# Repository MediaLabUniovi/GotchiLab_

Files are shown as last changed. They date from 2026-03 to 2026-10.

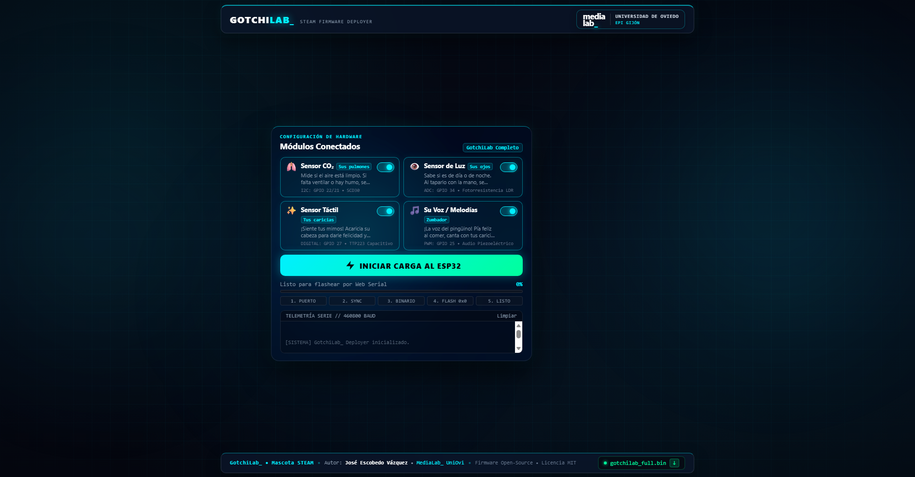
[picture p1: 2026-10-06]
docs/capturas/spotlight_capture.png

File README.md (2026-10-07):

# GotchiLab_








---

<div align="center">

  <a href="https://gotchilab.medialab-uniovi.es/" target="_blank" rel="noopener noreferrer">
    PULSA AQUÍ PARA CARGAR TU ESP32 ONLINE
  </a>

</div>

---

**GotchiLab_** es una mascota electrónica interactiva de código abierto diseñada y desarrollada en **MediaLab_** para talleres educativos de tecnología y divulgación **STEAM** (Ciencia, Tecnología, Ingeniería, Arte y Matemáticas).

La criatura virtual es un pingüino animado que habita en una pantalla OLED monocromática de 128x64 píxeles gobernada por un microcontrolador **ESP32 DevKit v1**. El firmware reacciona tanto a estímulos directos del usuario (pulsador de alimentación, caricias táctiles capacitivas, conmutador de sonido) como a magnitudes físicas ambientales (nivel de luminosidad mediante fotorresistencia LDR y concentración de dióxido de carbono $CO_2$ mediante sensor óptico NDIR).

---

## Índice

1. [Objetivos Educativos STEAM](#1-objetivos-educativos-steam)
2. [Arquitectura del Firmware y Ciclo de Vida](#2-arquitectura-del-firmware-y-ciclo-de-vida)
3. [Asignación de Pines (Pinout Unificado)](#3-asignación-de-pines-pinout-unificado)
4. [Ajuste y Calibración Analógica del Divisor LDR](#4-ajuste-y-calibración-analógica-del-divisor-ldr)
5. [Bypass Hardware de CO2: Modo Ferias y Demostraciones](#5-bypass-hardware-de-co2-modo-ferias-y-demostraciones)
6. [Máquina de Estados y Secuencia Gráfica de Muerte](#6-máquina-de-estados-y-secuencia-gráfica-de-muerte)
7. [Ciclo de Vida Autocontenido (Sin Persistencia)](#7-ciclo-de-vida-autocontenido-sin-persistencia)
8. [Guía de Compilación y Carga con PlatformIO](#8-guía-de-compilación-y-carga-con-platformio)
9. [GotchiLab_ Web Deployer & Flasheador Web Oficial (V4)](#9-gotchilab_-web-deployer--flasheador-web-oficial-v4)
10. [Estructura del Proyecto](#10-estructura-del-proyecto)
11. [Licencia](#11-licencia)

---

## 1. Objetivos Educativos STEAM

El proyecto busca desmitificar el desarrollo de sistemas embebidos mediante una experiencia tangible:
- **Electrónica Analógica y Digital**: Comprensión práctica de divisores resistivos, saturación de sensores LDR, buses de comunicación serie ($I^2C$), transductores piezoeléctricos PWM y sensores capacitivos táctiles.
- **Calidad del Aire y Conciencia Ambiental**: Introducción a la física de gases y sensores infrarrojos no dispersivos (NDIR) con el Sensirion SCD30, relacionando la concentración de $CO_2$ en recintos cerrados con la salud de la mascota.
- **Ingeniería de Software para Sistemas Embebidos**: Implementación de una Máquina de Estados Finita (FSM), eliminación de bloqueos (`delay()`) en favor de contadores no bloqueantes con `millis()`, gestión de buffers gráficos en RAM y modularidad tolerante a ausencias de hardware.

---

## 2. Arquitectura del Firmware y Ciclo de Vida

El sistema opera bajo un bucle cooperativo en tiempo real gobernado por `code/src/main.cpp`:
- **Capa Gráfica**: 15 cuadros monocromáticos de 128x64 píxeles por animación (1024 bytes/cuadro empaquetados en memoria Flash), renderizados a 5 FPS (200 ms por cuadro) con offsets verticales dinámicos.
- **Audio PWM**: Controlador de sonido sobre el canal 0 del generador LEDC del ESP32 con secuencias de notas no bloqueantes y conmutación de silencio por hardware.
- **Monitor de Constantes Vitales**: Evaluación periódica de hambre, afecto, fatiga por vigilia prolongada y toxicidad por $CO_2$.

```mermaid
flowchart TD
    EGG([Huevo IDLE_EGG]) -->|Toque TTP223 / Auto| BIRTH([Nacimiento BIRTH])
    BIRTH --> IDLE([Reposo Saludable IDLE])
    
    IDLE -->|Pulsador| FEED([Comiendo FEED])
    FEED --> IDLE
    
    IDLE -->|Toque TTP223| PET([Caricia PET])
    PET --> IDLE
    
    IDLE -->|Oscuridad LDR| SLEEP([Durmiendo SLEEP])
    SLEEP -->|Luz LDR| IDLE
    
    IDLE -->|CO2 >= 1600 ppm| T_UNHEALTHY([Transicion Enfermo])
    T_UNHEALTHY --> SICK([Reposo Enfermo IDLE_UNHEALTHY])
    SICK -->|CO2 <= 1100 ppm| T_HEALTHY([Transicion Sano])
    T_HEALTHY --> IDLE
    
    IDLE -.->|Inanicion / CO2 / Agotamiento / Spam| POP([Explosion POP - 15 Frames])
    SICK -.->|Inanicion / CO2 / Agotamiento| POP
    
    POP --> DEAD([Pantalla Game Over y Puntuacion])
    DEAD -->|Timeout 9s / Reset Pulsador tras 1.5s| EGG
```

---

## 3. Asignación de Pines (Pinout Unificado)

La arquitectura centraliza la asignación de pines en `code/include/pins_config.h`:

| Periférico / Señal | Pin ESP32 | Modo GPIO | Descripción Técnica |
| :--- | :---: | :---: | :--- |
| **I2C SDA** (OLED & SCD30) | `GPIO 22` | $I^2C$ Data | Bus de datos bidireccional compartido |
| **I2C SCL** (OLED & SCD30) | `GPIO 21` | $I^2C$ Clock | Señal de reloj de bus serie compartido |
| **Pulsador Alimentar** | `GPIO 33` | `INPUT_PULLUP` | Pulsador activo a nivel bajo (GND) |
| **Sensor Táctil (TTP223)** | `GPIO 27` | `INPUT` | Entrada digital activa a nivel alto (VCC) |
| **Sensor de Luz (LDR)** | `GPIO 34` | `ADC1_CH6` | Entrada analógica (solo lectura, sin pull-up) |
| **Buzzer Piezoeléctrico** | `GPIO 26` | Salida LEDC | Modulación PWM (Canal 0, 8 bits) |
| **Conmutador Silencio (Mute)** | `GPIO 32` | `INPUT_PULLUP` | Puente a GND conmuta entre sonido y silencio |
| **Modo Ferias (Bypass CO2)** | `GPIO 25` | `INPUT_PULLUP` | Jumper a GND: anula inicialización de $CO_2$ |

---

## 4. Ajuste y Calibración Analógica del Divisor LDR

### Topología del Circuito
El sensor de luz implementa un divisor de tensión resistivo entre la línea de 3.3V y masa:

```text
       3.3V (VCC)
           │
         ┌─┴─┐
         │LDR│ (Fotorresistencia)
         └─┬─┘
           ├───────> GPIO 34 (ADC1_CH6 del ESP32)
         ┌─┴─┐
         │10k│ (Resistencia Pull-Down de 10 kΩ)
         └─┬─┘
           │
          GND
```

### Ecuación de Transferencia
$$V_{out} = V_{CC} \cdot \left( \frac{R_{pull}}{R_{LDR} + R_{pull}} \right)$$

$$\text{Cuentas ADC (12 bits)} = \left( \frac{V_{out}}{3.3\,\text{V}} \right) \cdot 4095$$

- **En luz ambiente**: La resistencia $R_{LDR}$ cae a valores bajos (~1 kΩ a 5 kΩ), por lo que $V_{out} \approx 2.75\,\text{V}$ (ADC $\approx 3412$).
- **En oscuridad (tapado)**: La resistencia $R_{LDR}$ aumenta drásticamente (> 50 kΩ a 100+ kΩ), por lo que $V_{out}$ cae por debajo de $1.0\,\text{V}$ (ADC < 1240).

### Calibración Paso a Paso con Multímetro
1. Configura el multímetro en escala de tensión continua (**DC Voltios**, rango 20V o 2V).
2. Conecta la sonda negra a **GND** y la sonda roja al punto medio del divisor (**GPIO 34**).
3. Mide la tensión en condiciones de iluminación de trabajo ($V_{luz} \approx 2.5\,\text{V} - 3.0\,\text{V}$).
4. Cubre completamente la fotorresistencia con el dedo y anota la tensión mínima ($V_{oscuro} \approx 0.5\,\text{V} - 1.5\,\text{V}$).
5. Establece el punto de conmutación en el valor medio:
   $$V_{umbral} = \frac{V_{luz} + V_{oscuro}}{2}$$
   $$\text{LDR\_DARK\_THRESHOLD} = \left(\frac{V_{umbral}}{3.3\,\text{V}}\right) \cdot 4095$$
6. Actualiza la constante `LDR_DARK_THRESHOLD` en `code/include/config.h` (valor predeterminado: **2856**, correspondiente a ~2.30V).

### Telemetría Serie de Depuración
Para verificar lecturas en tiempo real sin cálculos manuales, activa la directiva en `code/include/config.h`:
```cpp
#define DEBUG_LDR_CALIBRATION 1
```
Abre la consola serie a **115200 baudios** para observar el volcado continuo:
```text
[LDR DEBUG] ADC Raw: 3120/4095 | Voltaje: 2.512 V | Umbral: 2856 | Estado: ILUMINADO (DESPIERTO)
[LDR DEBUG] ADC Raw: 1150/4095 | Voltaje: 0.926 V | Umbral: 2856 | Estado: OSCURO (DORMIR)
```

---

## 5. Bypass Hardware de CO2: Modo Ferias y Demostraciones

En eventos masivos, ferias de ciencias o aulas cerradas, la concentración de $CO_2$ suele superar con facilidad los 1600 ppm, provocando que la mascota enferme continuamente o muera por asfixia en menos de un minuto durante las explicaciones.

Para solventarlo sin recompilar el código:
1. **Jumper Físico**: Se define `PIN_FAIR_MODE` en `GPIO 25` configurado con `INPUT_PULLUP`.
2. **Detección en Arranque**: Durante el `setup()`, el microcontrolador verifica el estado de `GPIO 25`:
   - Si está conectado a **GND** mediante un jumper o cable Dupont:
     - Se omite la inicialización de la librería del sensor SCD30 y el tráfico por el bus $I^2C$.
     - La variable interna `co2SensorEnabled` pasa a `false`.
     - Las lecturas devuelven un valor nominal limpio y constante de **400 ppm**.
     - La máquina de estados ignora totalmente las penalizaciones y alertas respiratorias.
   - Si el jumper está abierto (flotante / HIGH): El sensor NDIR opera con normalidad.

### Exclusión Completa en Compilación
Si se construye una versión económica de la mascota sin el sensor Sensirion SCD30 instalado físicamente, puede excluirse íntegramente del binario definiendo en `code/include/config.h`:
```cpp
#define USE_CO2_SENSOR 0
```

---

## 6. Máquina de Estados y Secuencia Gráfica de Muerte

Para ofrecer un dramatismo lúdico intuitivo y eliminar transiciones abruptas:

1. **Detección de Fallecimiento**: Cuando se cumple cualquier condición crítica (inanición, asfixia por $CO_2$, privación de sueño o sobrealimentación), la función `triggerDeath(reason)` captura la causa y el timestamp.
2. **Ejecución Obligatoria de Animación "POP"**:
   - El sistema entra en el estado `POP` reproduciendo los 15 cuadros de explosión/desvanecimiento (`penguin_pop_anim`) a 200 ms por cuadro (3 segundos en total).
   - Se silencia cualquier sonido ambiental y se reproduce el efecto acústico de explosión.
3. **Transición a Pantalla de Game Over**:
   - Una vez finalizado el cuadro 14 de `POP`, la máquina conmuta formalmente a `DEAD`.
   - Se activa la marcha fúnebre mediante PWM.
   - Se limpia el buffer de vídeo y se imprime la esquela con:
     * Causa específica de defunción.
     * Segundos totales vividos tras la eclosión.
     * Cuidados totales (caricias táctiles y alimentaciones con éxito).
     * Puntuación matemática final.
4. **Buffer Libre de Parpadeos (*Flicker-Free*)**:
   - Todas las operaciones de renderizado se realizan exclusivamente en la memoria RAM del ESP32 (buffer de 1024 bytes de Adafruit_SSD1306).
   - La pantalla solo se actualiza en bloque mediante una única transacción $I^2C$ (`display.display()`), garantizando ausencia total de artefactos visuales.

---

## 7. Ciclo de Vida Autocontenido (Sin Persistencia)

Siguiendo la especificación de diseño educativo:
- **Cero Persistencia**: Se eliminan todas las dependencias de memoria no volátil (`Preferences.h`, `EEPROM.h`, NVS flash).
- **Reinicio Integral**: Al expirar el tiempo de la pantalla de muerte (9 segundos) o al presionar cualquier botón tras 1.5 segundos de gracia, la función `resetToEggState()` restablece de forma absoluta e incondicional todos los temporizadores, acumuladores de daño, banderas de estado, contadores de spam y variables de felicidad a sus valores base.
- Cada partida es un experimento nuevo, autónomo e independiente.

---

## 8. Guía de Compilación y Matriz Modular (PlatformIO)

### Requisitos Previos
- [PlatformIO Core (CLI)](https://docs.platformio.org/en/latest/core/index.html) o extensión oficial para [VS Code](https://code.visualstudio.com/).
- Cable USB de datos conectado al ESP32.

### Matriz Modular de Perfiles de Hardware (7 Variantes)
El firmware implementa desacoplamiento condicional mediante flags de preprocesador en `code/platformio.ini`, permitiendo generar binarios optimizados para cualquier combinación de periféricos:

| Entorno PlatformIO | CO₂ (SCD30) | Luz (LDR) | Táctil (TTP223) | Audio (Buzzer) | Descripción del Perfil |
| :--- | :---: | :---: | :---: | :---: | :--- |
| `full` (default) | ✅ Sí | ✅ Sí | ✅ Sí | ✅ Sí | Configuración completa oficial GotchiLab_ |
| `no_co2` | ❌ No | ✅ Sí | ✅ Sí | ✅ Sí | Recomendado: Optimización de coste de sensor óptico |
| `no_co2_silent` | ❌ No | ✅ Sí | ✅ Sí | ❌ No | Visual interactivo sin sonido ni sensor CO₂ |
| `no_co2_no_touch` | ❌ No | ✅ Sí | ❌ No | ✅ Sí | Modo auto-eclosión sin sensor capacitivo |
| `no_co2_no_light` | ❌ No | ❌ No | ✅ Sí | ✅ Sí | Modo siempre despierto sin ciclo día/noche |
| `minimal` | ❌ No | ❌ No | ❌ No | ❌ No | Solo OLED y pulsador de alimentación |
| `full_silent` | ✅ Sí | ✅ Sí | ✅ Sí | ❌ No | Monitoreo ambiental completo en silencio |

```bash
cd code

# Compilar una variante específica:
pio run -e no_co2

# O compilar todas las variantes simultáneamente:
pio run
```

---

## 9. GotchiLab_ Web Deployer & Flasheador Web Oficial (V4)

<div align="center">

  <a href="https://gotchilab.medialab-uniovi.es/" target="_blank" rel="noopener noreferrer">
    PULSA AQUÍ PARA CARGAR TU ESP32 ONLINE
  </a>

</div>

A partir de la versión **V4**, GotchiLab_ incorpora su propio entorno de programación web interactivo disponible directamente en la nube en **[gotchilab.medialab-uniovi.es](https://gotchilab.medialab-uniovi.es/)**, eliminando por completo la necesidad de instalar herramientas de desarrollo como VS Code, PlatformIO o Python para usuarios, familias y alumnos en talleres STEAM.

> [!TIP]
> ### 🚀 ¿Cómo cargar tu GotchiLab_ en 3 pasos?
> 1. **Conecta tu ESP32** al PC con un cable USB de datos.
> 2. **Abre el flasheador** en Google Chrome o Microsoft Edge: [gotchilab.medialab-uniovi.es](https://gotchilab.medialab-uniovi.es/).
> 3. **Elige tus sensores**, pulsa **"Conectar y Flashear"** y selecciona tu placa. ¡El pingüino cobrará vida en ~30 segundos!

### Características Principales:
1. **Flasheo Web Serial Nativo**: Integración directa con `esptool-js` en el navegador (Google Chrome / Microsoft Edge). Graba el microcontrolador por USB a 460800 baudios en offset unificado `0x00000000`.
2. **Simulador OLED en Vivo**: Canvas animado a 5 FPS que emula el display SSD1306 de 128x64 píxeles con la estética luminosa del pingüino en tiempo real (huevo, nacimiento, reposo, comida, mimos, sueño).
3. **Selector Dinámico de Sensores**: 4 interruptores interactivos (CO₂, Luz, Táctil y Voz) con descripciones pedagógicas. La interfaz resuelve automáticamente la variante binaria óptima del manifiesto (`web/data/manifest.json`).
4. **Consola de Telemetría Serie**: Terminal integrado en pantalla que muestra el progreso del flasheo en 5 etapas (Puerto, Sincronización, Descarga, Flash 0x0 y Verificación).

### Lanzamiento Local Rápido (1 Clic)
Para arrancar el deployer web localmente bajo un contexto seguro (`http://localhost:8000/web/`):
```cmd
iniciar_web.bat
```
El script inicia automáticamente un servidor HTTP local en Python y abre el navegador por defecto.

### Compilación y Empaquetado de la Matriz (`build_deploy.bat`)
Para compilar todas las variantes de firmware y generar los binarios unificados `0x0` listos para la web:
```cmd
build_deploy.bat
```
Este pipeline ejecuta `scripts/build_matrix.py`, que:
1. Compila los 7 perfiles PlatformIO.
2. Combina bootloader (`0x1000`), particiones (`0x8000`) y firmware (`0x10000`) en un único archivo fusionado por variante en `web/binaries/`.
3. Actualiza el manifiesto de versiones `web/data/manifest.json`.

---

## 10. Estructura del Proyecto

```text
GotchiLab_/
├── LICENSE                         # Licencia de software de código abierto MIT
├── README.md                       # Manual técnico y guía de ingeniería
├── prompt.md                       # Especificación maestra del sistema
├── GotchiLab_.pdf                  # Guía didáctica para talleres presenciales
├── iniciar_web.bat                 # Lanzador de un solo clic para el Flasheador Web local
├── docs/                           # Documentación auxiliar y capturas de interfaz
│   └── capturas/                   # Capturas del deployer y spotlight
├── Esquematico/                    # Esquemas Fritzing (.fzz), partes (.fzpz), PDF y PNG
├── PlacaSTL/                       # Archivos de fabricación 3D para chasis y PCB
├── VideoToCarray/                  # Pipeline Python/OpenCV para conversión de vídeo a C
├── scripts/
│   ├── build_matrix.py             # Compilador y unificador esptool de las 7 variantes
│   └── extract_animations.py       # Extractor de cuadros de animación a formato web
├── web/                            # GotchiLab_ Web Serial Deployer (V4)
│   ├── index.html                  # Panel de control de interfaz de usuario
│   ├── assets/                     # Identidad gráfica, iconos y botón web flasher
│   ├── css/
│   │   └── styles.css              # Estética Dark Cybernetic Lab & Glassmorphism
│   ├── js/
│   │   ├── app.js                  # Motor Web Serial, FSM visual y selector de hardware
│   │   ├── tour.js                 # Sistema de tutorial guiado interactivo (Spotlight)
│   │   └── animations.js           # Cuadros de animación 128x64 codificados en Base64
│   ├── data/
│   │   └── manifest.json           # Manifiesto JSON con las 7 variantes de firmware
│   └── binaries/                   # Binarios unificados (offset 0x00000000)
└── code/
    ├── platformio.ini              # Matriz de 7 perfiles modulares (ESP32 DevKit v1)
    ├── include/
    │   ├── pins_config.h           # Centralización de GPIOs y asignación de pines
    │   └── config.h                # Feature flags, umbrales y tiempos de supervivencia
    └── src/
        ├── main.cpp                # FSM principal, gestión gráfica, audio y loop vital
        ├── config/
        │   └── config.h            # Reenvío de compatibilidad hacia include/config.h
        ├── sensors/
        │   ├── sensors.h           # Declaración del subsistema de sensores
        │   └── sensors.cpp         # SCD30 con bypass y botón
        └── animations/             # Cuadros de animación monocromáticos en Flash (15 frames)
```

---

## 11. Licencia

Este proyecto está distribuido bajo la licencia de código abierto **MIT**. Consulta el archivo [LICENSE](LICENSE) para más detalles.

Desarrollado con pasión para la comunidad maker y educativa por **José Escobedo Vázquez** en **MediaLab_**.

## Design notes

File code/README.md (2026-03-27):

## Cómo funciona

El programa funciona como una máquina de estados.  
Eso significa que el personaje siempre está en una animación concreta (idle, comer, dormir, etc.) y cambia según lo que pase.

La variable principal es:
- currentAnimation → guarda el estado actual

Las animaciones se cambian usando:
- setAnimation(...)

## Animaciones

Cada animación:
- tiene varios frames (imágenes)
- cada frame es un array de bytes (bitmap)
- se dibuja en la pantalla con drawFrameRaw()

## Sensores (opcionales)

El código permite usar varios sensores, todos activables/desactivables con defines:

- Botón → dar de comer
- Distancia → detectar mano (caricia / nacimiento)
- Luz → dormir si está oscuro
- CO₂ (SCD4x) → estado “enfermo” si el aire es malo
- Buzzer → sonidos

Si un sensor no está conectado o se desactiva, esa funcionalidad desaparece automáticamente.

## Lógica básica

- Empieza como huevo
- Nace (por sensor o automáticamente)
- Entra en estado normal (idle)
- Cambia según:
  - botón → comer
  - mano → caricia
  - oscuridad → dormir
  - CO₂ alto → estado malo

Si mejora el CO₂:
- vuelve a estado normal usando la animación al revés

## CO₂ (importante)

Se usa histéresis:
- entra en “malo” con CO₂ alto
- solo vuelve a “bien” cuando baja suficiente

Esto evita cambios constantes.

## Animaciones inversas

Las transiciones se reutilizan:
- ida → frames normales
- vuelta → mismos frames pero al revés

## Sonido

Los sonidos son listas de notas:
- frecuencia + duración

Cada animación puede tener su sonido.

## Qué puedes modificar

- Activar sensores (defines)
- Umbrales (luz, distancia, CO₂)
- Velocidad de animación (FRAME_TIME_MS)
- Sonidos
- Añadir nuevas animaciones

## Resumen

- Sistema basado en estados
- Animaciones en arrays
- Sensores controlan el comportamiento
- Todo modular y opcional

Pensado para que sea fácil de ampliar y modificar.

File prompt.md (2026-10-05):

# SYSTEM PROMPT & SPECIFICATION: GOTCHILAB_

> **Propósito de este archivo**: Este documento (`prompt.md`) actúa como la especificación técnica completa y plantilla de prompt para generar desde cero, comprender, mantener y extender el proyecto **GotchiLab_**. Puede suministrarse a cualquier LLM / agente de código o desarrollador para reconstruir o ampliar el sistema de forma consistente con su arquitectura y diseño modular original.

---

## 1. Visión General del Proyecto

**GotchiLab_** es una mascota electrónica interactiva (tipo Tamagotchi educativo) diseñada en **MediaLab_** para talleres formativos y divulgación STEAM.
La mascota es un pingüino animado en una pantalla OLED monocromática de 128x64 píxeles controlada por un microcontrolador **ESP32 DevKit v1**. El comportamiento de la criatura reacciona tanto a interacciones táctiles y pulsadores como a variables ambientales (luz y niveles de dióxido de carbono $CO_2$) y cuenta con un sistema de muteo por hardware y constantes vitales en segundo plano.

### Características Clave:
- **Modularidad por Hardware**: Arquitectura desacoplada mediante directivas de precompilación (`#define USE_*_SENSOR`). Si un sensor no está físicamente conectado, el firmware ajusta su comportamiento dinámicamente sin fallos ni bloqueos.
- **Máquina de Estados Finita (FSM)**: Estados bien diferenciados para huevo, nacimiento, reposo, caricia, alimentación, sueño, transición ambiental (sano/enfermo), sobrealimentación (explosión) y muerte (`DEAD`).
- **Modo Inmersivo (Estados en Segundo Plano)**: Pantalla limpia de 128x64 dedicada en su totalidad a las animaciones; los estados de hambre, felicidad, cansancio y $CO_2$ operan de fondo obligando a un cuidado intuitivo continuo.
- **Control de Silencio por Hardware (`MUTE_PIN`)**: Pin GPIO 27 con pull-up que, al puentearse a tierra (GND), conmuta entre modo silencioso y modo con volumen (con tono confirmatorio).
- **Animaciones en Memoria Flash**: Animaciones monocromáticas de 15 cuadros (128x64 píxeles, 1024 bytes/cuadro, 5 FPS, 200 ms/cuadro) con arrays de desplazamiento vertical (`yOffset`).
- **Retroalimentación Sonora**: Buzzer pasivo controlado por PWM (`ledc`) con secuencias de notas no bloqueantes y marcha fúnebre en Game Over.
- **Herramientas Auxiliares de Pipeline**: Script en Python con OpenCV (`mp4_a_c_array_v2.py`) para convertir vídeos MP4 directamente a arrays binarios en C/C++ compatibles con el display OLED SSD1306.

---

## 2. Diagrama de Contexto del Sistema

```mermaid
flowchart TB
    %% Actores Externos
    subgraph Actores_Externos ["ACTORES EXTERNOS"]
        Usuario["👤 Niño / Usuario\n(Interacción física, caricias, comida, mute)"]
        Entorno["🌍 Entorno Físico\n(Luz ambiental y Calidad del Aire)"]
    end

    %% Límites del Sistema GotchiLab_
    subgraph GotchiLab_Sistema ["SISTEMA EMBEBIDO GOTCHILAB_ (ESP32)"]
        
        subgraph Entradas_Sensoriales ["Capa de Sensores / Entradas"]
            Touch["Sensor Táctil Capacitivo\n(TTP223 / GPIO 14)"]
            Btn["Pulsador Push Button\n(INPUT_PULLUP / GPIO 33)"]
            LDR["Sensor de Luz LDR\n(Divisor 10kΩ / GPIO 34)"]
            SCD30["Sensor NDIR CO₂\n(SCD30 I2C 0x61 / SDA:22, SCL:21)"]
            MutePin["Pin Mute / Silencio\n(INPUT_PULLUP / GPIO 27)"]
        end

        subgraph Core_Firmware ["Núcleo de Control y Lógica"]
            FSM["Máquina de Estados (FSM)\n(Egg, Birth, Idle, Feed, Pet, Sleep, Pop, Unhealthy, Dead)"]
            StatsCore["Vigilante de Constantes Vitales\n(Hambre 3m, Sueño Progresivo, CO₂, Felicidad)"]
            ConfigMod["Capa de Configuración Modular\n(config.h - Feature Flags)"]
            SensorMgr["Manejador de Sensores\n(sensors.cpp / sensors.h)"]
            AnimEngine["Motor de Renderizado Gráfico\n(drawFrameRaw + yOffsets)"]
            AudioEngine["Controlador de Audio PWM\n(ledcWriteTone / Secuencias / Mute Toggle)"]
        end

        subgraph Actuadores_Salidas ["Capa de Salidas / Actuadores"]
            OLED["Pantalla OLED 128x64 SSD1306\n(I2C 0x3C / SDA:22, SCL:21)"]
            Buzzer["Buzzer Pasivo\n(PWM LEDC / GPIO 26)"]
            SerialMon["Consola Serie / Telemetría\n(UART 115200 baudios)"]
        end
    end

    %% Herramientas Externas
    subgraph Herramientas_Soporte ["HERRAMIENTAS AUXILIARES / WORKFLOW"]
        VideoScript["Conversor Python\n(mp4_a_c_array_v2.py)"]
        VisoresHTML["Visores Web de Verificación\n(HTML5 Canvas)"]
    end

    %% Relaciones / Flujos
    Usuario -- "Toca sensor" --> Touch
    Usuario -- "Pulsa para alimentar" --> Btn
    Usuario -- "Puentea a GND para silenciar" --> MutePin
    Entorno -- "Nivel de luminosidad" --> LDR
    Entorno -- "Concentración CO₂ (ppm)" --> SCD30

    Touch --> SensorMgr
    Btn --> SensorMgr
    LDR --> SensorMgr
    SCD30 --> SensorMgr
    MutePin --> AudioEngine

    ConfigMod -. "Habilita / Deshabilita módulos" .-> SensorMgr
    ConfigMod -. "Tiempos, umbrales y pines" .-> FSM
    SensorMgr --> FSM
    FSM <--> StatsCore

    FSM --> AnimEngine
    FSM --> AudioEngine

    AnimEngine -- "I2C Frames 128x64" --> OLED
    AudioEngine -- "PWM Frecuencias" --> Buzzer
    FSM -- "Logs de estado" --> SerialMon

    VideoScript -. "Genera arrays .c/.h de animación" .-> AnimEngine
    VisoresHTML -. "Previsualiza frames" .- VideoScript
```

---

## 3. Especificación Técnica de Hardware y Pines

### 3.1 Lista de Componentes (BOM)
1. **Microcontrolador**: ESP32 DevKit v1 (30 o 36 pines).
2. **Display**: Pantalla OLED 0.96" SSD1306 I2C (128x64, dirección 0x3C).
3. **Sensor CO₂**: Sensirion SCD30 (NDIR óptico de alta precisión, interfaz I2C).
4. **Sensor Táctil**: TTP223 módulo capacitivo digital.
5. **Sensor de Luz**: Fotorresistencia LDR en divisor de tensión con resistencia pull-down de 10kΩ.
6. **Actuador Sonoro**: Buzzer piezoeléctrico pasivo.
7. **Pulsador**: Pulsador normalmente abierto (NA).
8. **Placa de pruebas**: Protoboard y cableado Dupont.

### 3.2 Asignación de Pines (Pinout)

Todas las asignaciones están centralizadas en `include/pins_config.h`:

| Componente | Pin ESP32 | Modo / Configuración | Función |
| :--- | :---: | :--- | :--- |
| **OLED SDA** | GPIO 22 | I2C Data (Wire) | Bus de datos display (compartido) |
| **OLED SCL** | GPIO 21 | I2C Clock (Wire) | Bus de reloj display (compartido) |
| **SCD30 SDA** | GPIO 22 | I2C Data (Wire) | Bus de datos sensor CO₂ |
| **SCD30 SCL** | GPIO 21 | I2C Clock (Wire) | Bus de reloj sensor CO₂ |
| **Pulsador** | GPIO 33 | `INPUT_PULLUP` | Detección de pulsación a GND (Comer / Spam) |
| **Sensor Touch** | GPIO 27 | `INPUT` digital | Señal digital HIGH cuando se toca (Caricia / Nacer) |
| **Sensor Luz (LDR)** | GPIO 34 | `INPUT` analógico (ADC1_CH6) | Lectura de voltaje de luminosidad (11dB / 12 bits) |
| **Buzzer** | GPIO 26 | Salida LEDC (Canal 0) | Generación de tonos audibles mediante PWM |
| **Mute (Silencio)** | GPIO 32 | `INPUT_PULLUP` | Puentear a GND conmuta entre silencio y sonido |
| **Modo Ferias (Bypass CO₂)** | GPIO 25 | `INPUT_PULLUP` | Jumper a GND: anula inicialización de CO₂ |

---

## 4. Estructura de Archivos del Proyecto

```text
GotchiLab_/
├── LICENSE                         # Licencia de código abierto MIT
├── README.md                       # Documentación técnica completa del repositorio
├── prompt.md                       # ESTE ARCHIVO: Especificación maestra y prompt de generación
├── GotchiLab_.pdf                  # Documento didáctico para participantes del taller
├── Esquematico/                    # Esquemas Fritzing (.fzz), partes (.fzpz), PDF y PNG
├── PlacaSTL/                       # Modelos 3D de caja y PCB
├── VideoToCarray/                  # Herramientas de extracción de frames
│   ├── mp4_a_c_array_v2.py         # Script Python de vídeo a arrays C empaquetados
│   ├── ComprobarBitArray.html      # Test de formato y bits
│   ├── VisorAnimacionCArrayOLED.html # Simulador web de animación en display OLED
│   └── Recursos/                   # Vídeos fuente MP4 y assets
└── code/
    ├── platformio.ini              # Configuración PlatformIO (ESP32 DevKit v1)
    ├── include/
    │   ├── pins_config.h           # Centralización de GPIOs y asignación de pines
    │   └── config.h                # Feature flags, umbrales y tiempos de juego
    └── src/
        ├── main.cpp                # FSM principal, audio, mute, animación POP y ciclo de vida limpio
        ├── config/
        │   └── config.h            # Reenvío de compatibilidad hacia include/config.h
        ├── sensors/
        │   ├── sensors.h           # Declaración del subsistema de sensores con bypass modo ferias
        │   └── sensors.cpp         # Implementación SCD30 y botón con bypass
        └── animations/             # Arrays C con frames monocromáticos y offsets
            ├── penguin_birth_anim.[c|h]
            ├── penguin_feed_anim.[c|h]
            ├── penguin_idle_anim.[c|h]
            ├── penguin_idle_egg_anim.[c|h]
            ├── penguin_idle_unhealthy_anim.[c|h]
            ├── penguin_pet_anim.[c|h]
            ├── penguin_pop_anim.[c|h]
            ├── penguin_sleep_anim.[c|h]
            └── penguin_transition_unhealthy_anim.[c|h]
```

---

## 5. Arquitectura del Firmware y Lógica de Estados (FSM)

### 5.1 Definición de Estados (`AnimationState`)
```cpp
enum AnimationState {
    FEED = 0,                    // Comiendo (bloqueante)
    IDLE = 1,                    // Pingüino sano en reposo
    PET = 2,                     // Recibiendo caricia (bloqueante)
    SLEEP = 3,                   // Dormido (pausado en frame 10 mientras siga oscuro)
    POP = 4,                     // Sobrealimentado / Explosión (bloqueante)
    IDLE_EGG = 5,                // Huevo esperando eclosión
    BIRTH = 6,                   // Eclosión / Nacimiento (bloqueante)
    IDLE_UNHEALTHY = 7,          // Pingüino enfermo (CO₂ alto)
    TRANSITION_TO_UNHEALTHY = 8, // Transición de sano a enfermo (bloqueante)
    TRANSITION_TO_HEALTHY = 9,   // Transición de regreso a sano (reversa, bloqueante)
    DEAD = 10                    // Pantalla de Game Over y cálculo de puntuación
};
```

### 5.2 Reglas de Supervivencia, Alertas Acústicas y Muerte
1. **Inanición (3 minutos)**: Si transcurren más de `STARVATION_TIME_MS` (180,000 ms) sin alimentar al pingüino, muere por inanición.
   - *Alerta Acústica de Hambre*: A partir de 1 minuto sin comer (`HUNGER_ALERT_TIME_MS`), genera un sonido realista de **estómago rugiendo** (`SOUND_HUNGER_GROWL`) cada 20 segundos.
2. **Sobrealimentación (`POP`) y Protección de Nacimiento**:
   - Si se pulsa el botón 5 veces en menos de 2.2 segundos, explota y muere (`POP`).
   - *Inmunidad antes y durante el Nacimiento*: Antes de nacer (huevo `IDLE_EGG` o animación `BIRTH`), pulsar el botón no acumula spam ni produce muertes. Además, cuenta con un período de gracia de 5 segundos tras nacer (`NEWBORN_GRACE_PERIOD_MS`) inmune a sobrealimentación por pulsaciones rápidas.
3. **Asfixia por $CO_2$**: Activación a $\ge 1600\text{ ppm}$ y recuperación a $\le 1100\text{ ppm}$. Si acumula 60 segundos continuos en atmósfera contaminada (`MAX_CO2_EXPOSURE_MS`), muere por asfixia.
   - *Alerta Acústica de Enfermo / Tos*: Mientras el $CO_2$ esté alto, tose periódicamente (`SOUND_COUGH`, cada 12 segundos) simulando carraspeos secos por el aire viciado.
4. **Agotamiento Extremo (2.5 minutos)**: Si permanece despierto sin descanso, acumula fatiga. Al apagar la luz / tapar el LDR, recupera energía de forma progresiva (3x más rápido). Si no duerme en 150 segundos, muere por agotamiento.
   - *Alerta Acústica de Sueño*: Si permanece despierto más de 70 segundos (`SLEEP_ALERT_TIME_MS`), emite periódicamente una **melodía somnolienta descendente** dulce (`SOUND_SLEEPY`) pidiendo descansar, la cual también sirve de nana al entrar en modo sueño.
5. **Game Over, Puntuación y Reinicio**:
   $$\text{Puntuación} = (T_{\text{vivo}} \times 10) + (N_{\text{comidas}} \times 15) + (N_{\text{caricias}} \times 20) - \text{Penalizaciones}$$
   La pantalla final se muestra durante 9 segundos (o se reinicia inmediatamente si el usuario pulsa botón o touch tras 1.5s). Al volver al huevo, **absolutamente todos los valores, acumuladores, estadísticas, frecuencias de buzzer y timestamps se reinician desde cero**.

---

## 6. Configuración de Módulos Opcionales (`config.h`)

```c
#define USE_BUTTON_SENSOR       1  // 0: Sin botón ni muerte por hambre
#define USE_TOUCH_SENSOR        1  // 0: Eclosión automática y sin caricias
#define USE_LIGHT_SENSOR        1  // 0: Sin modo sueño ni muerte por agotamiento
#define USE_CO2_SENSOR          1  // 0: Siempre sano a 400 ppm
#define USE_BUZZER              1  // 0: Modo silencioso total
#define SHOW_STATS_OVERLAY      0  // 0: Modo inmersivo pantalla limpia, 1: HUD visible
```

---

## 7. Prompt Operativo para LLMs / Agentes de Código

Copia y pega el siguiente bloque como instrucción para cualquier LLM cuando quieras que trabaje sobre este proyecto:

```markdown
Eres el ingeniero de firmware y hardware responsable de GotchiLab_.
Actúa basándote en las especificaciones del archivo `prompt.md`:
1. El proyecto corre en ESP32 DevKit v1 usando PlatformIO / Arduino Framework.
2. La arquitectura debe mantener la modularidad absoluta (#if USE_*_SENSOR). No asumas que todos los periféricos están conectados.
3. El loop principal (`loop()`) es completamente asíncrono y no bloqueante mediante contadores `millis()`.
4. Toda nueva animación debe cumplir el formato de 15 frames, 128x64 bits y array de offsets.
5. El buzzer utiliza el canal LEDC 0 de ESP32 sin bloquear la CPU y respeta el estado de silencio en GPIO 27 (MUTE_PIN).
6. Si sugieres cambios o nuevo código, entrega el diff o el código completo respetando la estructura modular `config.h`, `sensors/`, `animations/` y `main.cpp`.
```

---

## 8. Ecosistema de Despliegue Web y Matriz Modular (V4)

- **Flasheo Web Serial Directo (`web/`)**: Interfaz gráfica construida con `esptool-js` para programar el ESP32 desde Google Chrome o Microsoft Edge vía USB a 460800 baudios en offset `0x00000000` sin instalar controladores ni compiladores.
- **Simulador OLED en Vivo**: Canvas HTML5 animado a 5 FPS que emula el display SSD1306 (128x64) con la estética luminosa del pingüino en tiempo real.
- **Matriz Modular de 7 Binarios**: Pipeline automatizado (`scripts/build_matrix.py` y `build_deploy.bat`) que compila las 7 variantes de hardware de `code/platformio.ini` y genera imágenes unificadas `0x0` combinando bootloader, tabla de particiones y firmware.
- **Lanzador Local Seguro (`iniciar_web.bat`)**: Script de un clic para Windows que arranca un servidor HTTP local en `http://localhost:8000/web/` garantizando un contexto seguro para la Web Serial API.

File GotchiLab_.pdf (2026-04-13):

# Nuestro Pingüinito Electrónico

### Proyecto del Medialab

Hoy vamos a construir una pequeña mascota electrónica.

Nuestro pingüinito empieza dentro de un huevo. Cuando lo tocamos...
¡El pingüino nace!
Después podremos:
darle de comer
acariciarlo
hacer que se duerma
escuchar sus soniditos
ver si está contento o enfermito

## ¿Cómo entiende lo que hacemos?

El botón
Cuando pulsamos el botón es como si cerráramos un pequeño puente para que la electricidad pase.
Entonces el pingüinito entiende:
¡Me están dando comida!

El sensor táctil
Este sensor funciona cuando lo tocamos con el dedo.
Es como si el pingüinito sintiera nuestro toque.
si el pingüino está en el huevo, al tocarlo... ¡nace!
si ya ha nacido, al tocarlo piensa: ¡Me están acariciando!

El sensor de luz
Este sensor es como los ojitos del pingüinito. si hay luz está despierto
si está oscuro se duerme

El sensor de aire
Este sensor mira cómo está el aire.
A veces el aire está bien y a veces no tanto.
si el aire está bien, el pingüinito está sano
si el aire se pone mal, el pingüinito se pone enfermito Cuando el aire vuelve a estar bien...
¡el pingüinito se recupera!

El buzzer
El buzzer es la vocecita del pingüinito. Hace pequeños sonidos cuando:
nace
come
lo acariciamos
se va a dormir
¡explota!

## Cuidado con darle demasiada comida

Si pulsas el botón de comida muchas veces muy rápido...
¡El pingüino explota!
Entonces el juego vuelve a empezar.
El pingüino vuelve al huevo y tendrás que hacerlo nacer otra vez.

## Ahora prueba

Prueba estas cosas:
toca el sensor táctil para que el pingüino nazca pulsa el botón para darle comida
vuelve a tocar el sensor táctil para acariciarlo tapa el sensor de luz para que se duerma ¿Qué crees que pasa si el aire no está bien?

## Conexiones y esquema

COMPONENTE | ESP32
Pantalla VCC Pantalla GND Pantalla SDA Pantalla SCL | 3.3V GND D22 D21

Botón pin 1 (diagonal)

Botón pin 2 (diagonal)

D33

GND

Touch OUT

Touch VCC

Touch GND

D14

3.3V

GND

SCD30 VCC

SCD30 GND

SCD30 SDA

SCD30 SCL

3.3V

GND

D22

D21

3.3V | LDR | D34
GND | Res 10kΩ | D34

Buzzer +

Buzzer -

D26

GND

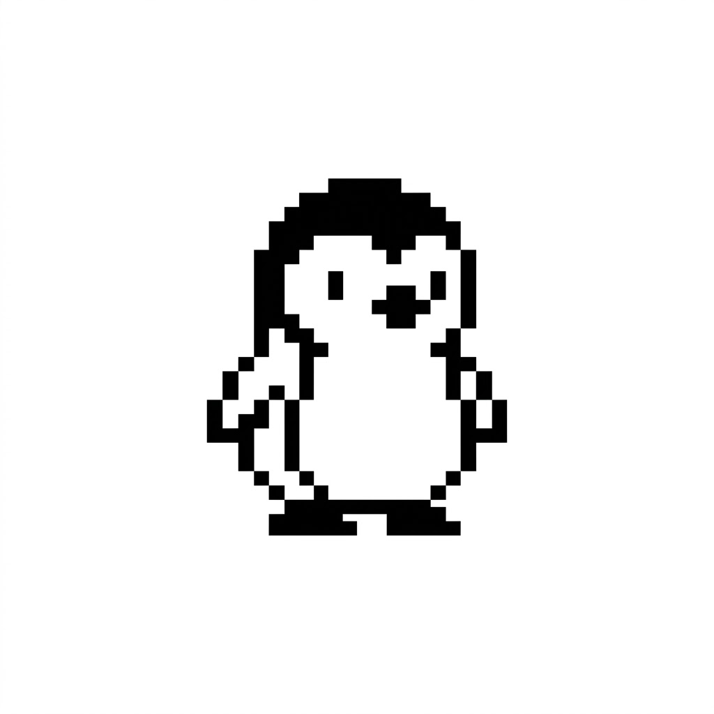
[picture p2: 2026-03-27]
VideoToCarray/Recursos/Gotchi.png

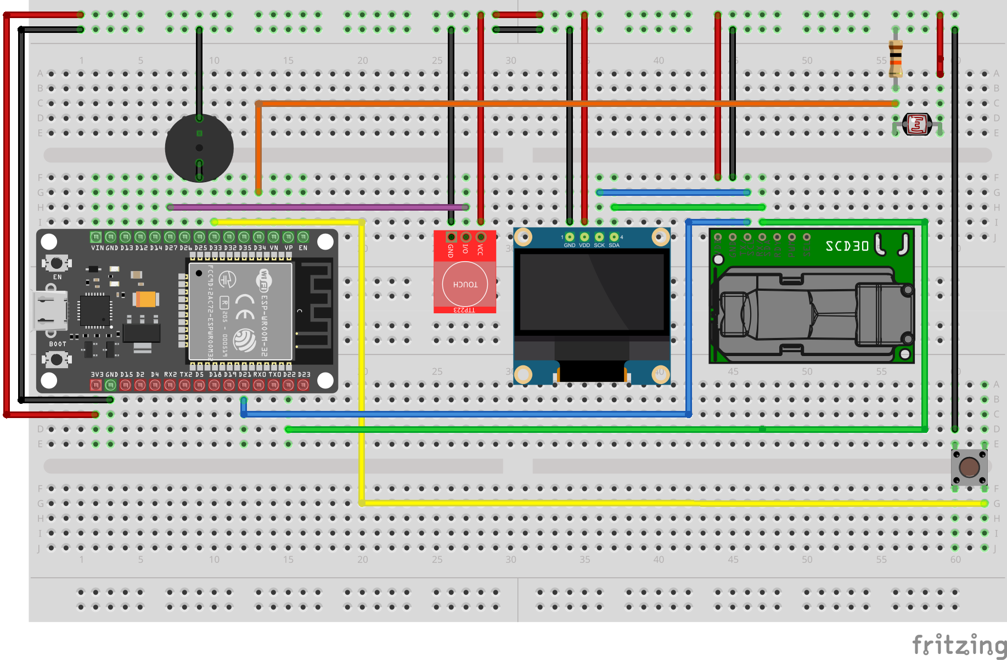
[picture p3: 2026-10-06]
Esquematico/Esquematico.png

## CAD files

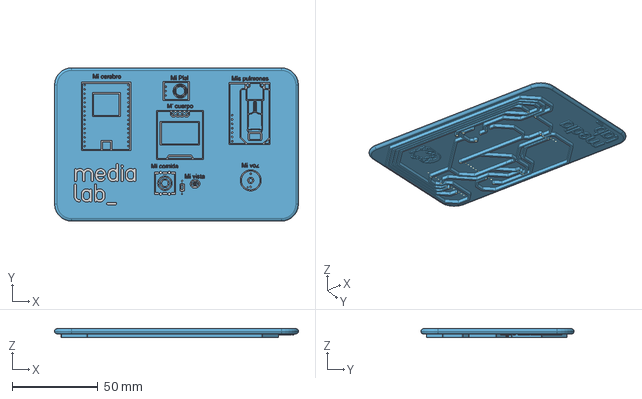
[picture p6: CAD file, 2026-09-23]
PlacaSTL/PlacaGotchiLab_.step
142.0 x 89.3 x 5.00 mm

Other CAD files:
PlacaSTL/PlacaGotchiLab_.3mf
PlacaSTL/PlacaGotchiLab_.f3d

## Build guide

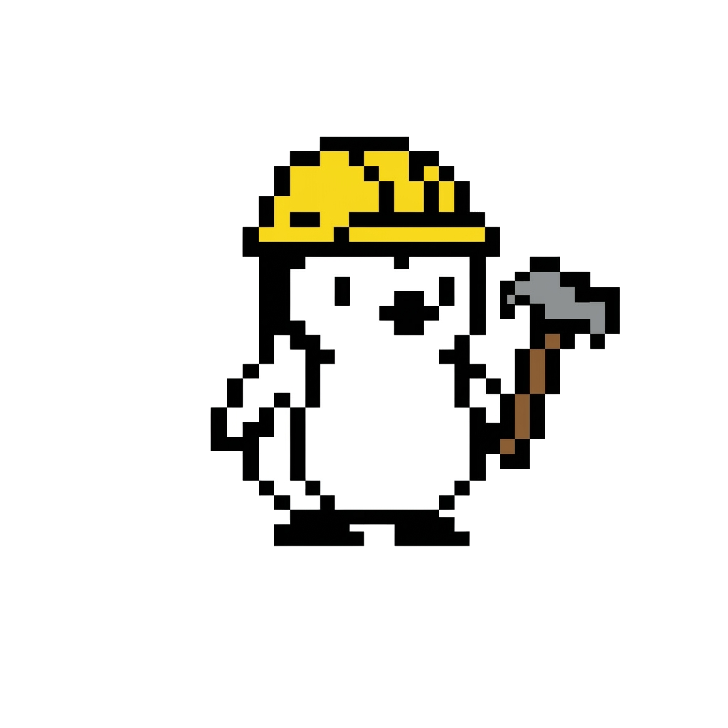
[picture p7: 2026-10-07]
docs/pinguino_construccion_transp.png

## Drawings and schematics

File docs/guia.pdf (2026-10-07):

# GOTCHILAB_

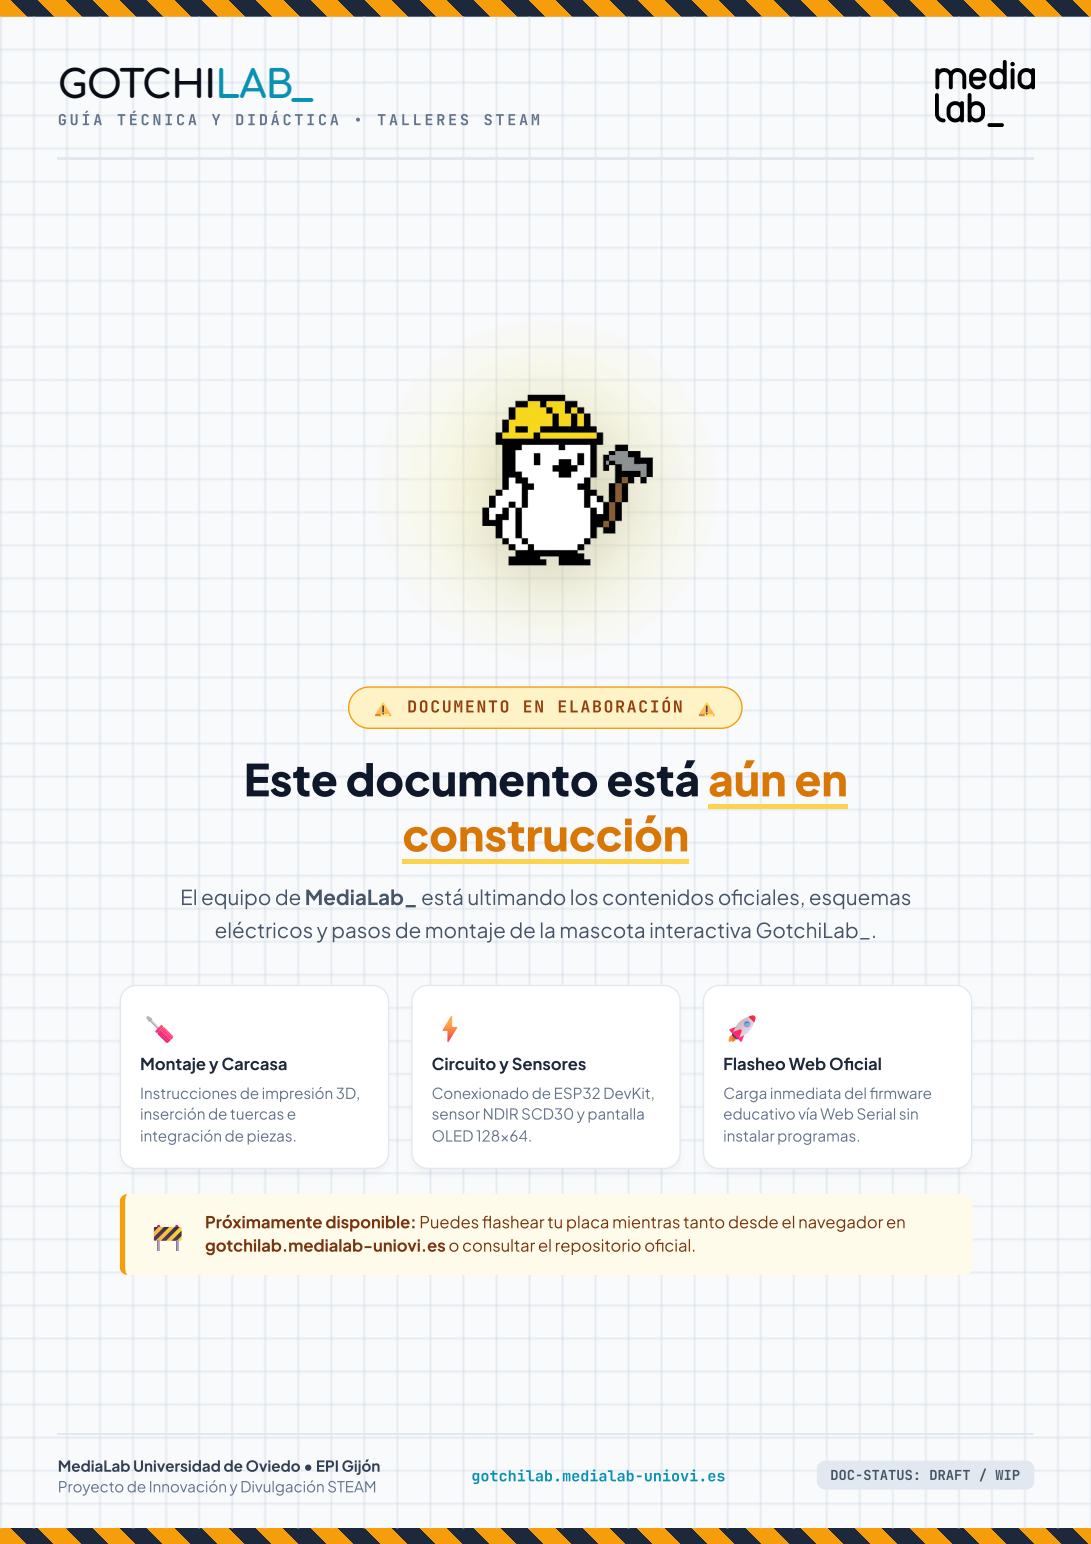
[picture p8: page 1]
⚠️ DOCUMENTO EN ELABORACIÓN; construcción; Montaje y Carcasa; Circuito y Sensores; OLED 128x64.; instalar programas.; gotchilab.medialab-uniovi.es; DOC-STATUS: DRAFT / WIP

Este documento está aún en

El equipo de MediaLab_ está ultimando los contenidos oficiales, esquemas

eléctricos y pasos de montaje de la mascota interactiva GotchiLab_.

Flasheo Web Oficial

Instrucciones de impresión 3D,
inserción de tuercas e

Conexionado de ESP32 DevKit,
sensor NDIR SCD30 y pantalla

Carga inmediata del firmware
educativo vía Web Serial sin

integración de piezas.

🚧 Próximamente disponible: Puedes flasheartu placa mientras tanto desde el navegador en

gotchilab.medialab-uniovi.es o consultar el repositorio oficial.

MediaLab Universidad de Oviedo • EPI Gijón

Proyecto de Innovación y Divulgación STEAM

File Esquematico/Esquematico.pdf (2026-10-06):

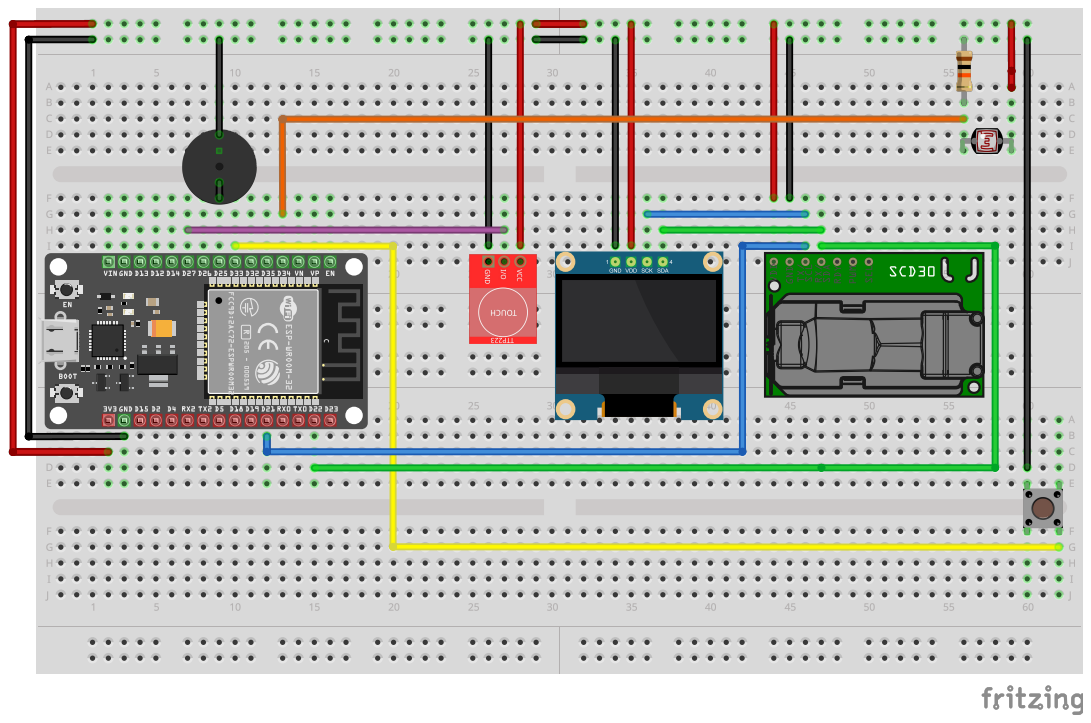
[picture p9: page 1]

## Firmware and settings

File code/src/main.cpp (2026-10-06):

/**
 * @file main.cpp
 * @brief GotchiLab_ - Firmware Principal de Mascota Virtual Educativa STEAM.
 * @author José Escobedo Vázquez / MediaLab_
 * @license MIT
 *
 * Arquitectura modular sobre ESP32 DevKit v1 con display OLED SSD1306,
 * sensor NDIR Sensirion SCD30, fotorresistencia LDR calibrada y actuador piezoeléctrico.
 */

#include <Arduino.h>
#include <Wire.h>
#include <Adafruit_GFX.h>
#include <Adafruit_SSD1306.h>

#include "config/config.h"
#include "sensors/sensors.h"

extern "C" {
    #include "animations/penguin_feed_anim.h"
    #include "animations/penguin_idle_anim.h"
    #include "animations/penguin_pet_anim.h"
    #include "animations/penguin_sleep_anim.h"
    #include "animations/penguin_pop_anim.h"
    #include "animations/penguin_idle_egg_anim.h"
    #include "animations/penguin_birth_anim.h"
    #include "animations/penguin_idle_unhealthy_anim.h"
    #include "animations/penguin_transition_unhealthy_anim.h"
}

/* ========================================================================== */
/* HARDWARE INSTANCES & BITMAPS                                               */
/* ========================================================================== */

static Adafruit_SSD1306 display(SCREEN_WIDTH, SCREEN_HEIGHT, &Wire, OLED_RESET);

/// Icono bitmap 1-bit de muslo de comida para HUD (5x5 px)
static const unsigned char PROGMEM chicken_leg_icon[] = {
    0b01110000,
    0b11111000,
    0b11110000,
    0b01100000,
    0b00110000
};

/* ========================================================================== */
/* FSM & LIFE CYCLE ENUMS                                                     */
/* ========================================================================== */

/**
 * @brief Estados principales de la Máquina de Estados Finita (FSM).
 */
enum AnimationState {
    FEED = 0,                    ///< Comiendo alimento (bloqueante)
    IDLE = 1,                    ///< Reposo en estado saludable
    PET = 2,                     ///< Recibiendo caricia táctil (bloqueante)
    SLEEP = 3,                   ///< Durmiendo en penumbra
    POP = 4,                     ///< Animación de explosión/desvanecimiento post-mortem (bloqueante)
    IDLE_EGG = 5,                ///< Huevo esperando eclosión
    BIRTH = 6,                   ///< Eclosión y nacimiento (bloqueante)
    IDLE_UNHEALTHY = 7,          ///< Reposo enfermo por atmósfera viciada (CO2 alto)
    TRANSITION_TO_UNHEALTHY = 8, ///< Transición gráfica hacia estado enfermo
    TRANSITION_TO_HEALTHY = 9,   ///< Transición de recuperación hacia estado sano
    DEAD = 10                    ///< Pantalla final de defunción y Game Over
};

/**
 * @brief Razones clínicas de fallecimiento de la criatura.
 */
enum DeathReason {
    DEATH_NONE = 0,
    DEATH_STARVATION,            ///< Inanición por falta de alimento (> 3 minutos)
    DEATH_OVERFED,               ///< Sobrealimentación crítica por spam de pulsaciones (POP)
    DEATH_CO2,                   ///< Asfixia por exposición continua a CO2 (> 60 segundos)
    DEATH_EXHAUSTION             ///< Agotamiento extremo por falta de descanso (> 2.5 minutos)
};

static AnimationState currentAnimation = IDLE_EGG;
static uint8_t currentFrame = 0;

static DeathReason pendingDeathReason = DEATH_NONE;
static DeathReason deathReason = DEATH_NONE;
static uint32_t deathTime = 0;

/* ========================================================================== */
/* AUDIO SYSTEM & TONE TABLES                                                 */
/* ========================================================================== */

struct Note {
    uint16_t freq;
    uint16_t duration;
};

static const Note SOUND_FEED[] = {
    {523, 70}, {659, 70}, {784, 90}, {1047, 120}, {0, 30}
};

static const Note SOUND_PET[] = {
    {659, 60}, {784, 60}, {659, 80}, {0, 25}
};

static const Note SOUND_IDLE[] = {
    {523, 40}, {659, 50}, {0, 20}
};

static const Note SOUND_SLEEPY[] = {
    {784, 130}, {659, 150}, {587, 170}, {523, 200},
    {0, 60},
    {440, 200}, {392, 230}, {330, 280}, {262, 400}, {0, 80}
};

static const Note SOUND_SLEEP[] = {
    {784, 130}, {659, 150}, {587, 170}, {523, 200},
    {0, 60},
    {440, 200}, {392, 230}, {330, 280}, {262, 400}, {0, 80}
};

static const Note SOUND_HUNGER_GROWL[] = {
    {98, 90}, {115, 80}, {82, 100}, {123, 70}, {75, 120},
    {0, 40},
    {87, 100}, {110, 80}, {92, 90}, {73, 140}, {0, 60}
};

static const Note SOUND_COUGH[] = {
    {370, 35}, {240, 45}, {140, 60}, {0, 70},
    {390, 35}, {260, 45}, {150, 70}, {0, 90},
    {310, 40}, {200, 50}, {120, 80}, {0, 60}
};

static const Note SOUND_EGG[] = {
    {392, 70}, {440, 70}, {392, 80}, {0, 40}
};

static const Note SOUND_BIRTH[] = {
    {523, 60}, {659, 60}, {784, 60}, {988, 80}, {1175, 110}, {0, 40}
};

static const Note SOUND_POP[] = {
    {220, 40}, {180, 35}, {140, 35}, {90, 70}, {0, 30}
};

static const Note SOUND_UNHEALTHY[] = {
    {370, 35}, {240, 45}, {140, 60}, {0, 70},
    {390, 35}, {260, 45}, {150, 70}, {0, 60}
};

static const Note SOUND_TRANSITION_UNHEALTHY[] = {
    {587, 60}, {523, 70}, {440, 80}, {0, 30},
    {370, 40}, {240, 50}, {140, 70}, {0, 40}
};

static const Note SOUND_TRANSITION_RECOVER[] = {
    {440, 60}, {523, 70}, {659, 90}, {0, 30}
};

static const Note SOUND_DEATH[] = {
    {440, 300}, {440, 300}, {440, 300}, {349, 250}, {523, 100},
    {440, 300}, {349, 250}, {523, 100}, {440, 600}, {0, 100}
};

static const Note* currentSound = nullptr;
static uint8_t currentSoundLength = 0;
static uint8_t currentSoundIndex = 0;
static bool soundPlaying = false;
static uint32_t soundLastChange = 0;

/* ========================================================================== */
/* STATE VARIABLES & TELEMETRY TIMERS                                         */
/* ========================================================================== */

static uint32_t lastButtonTime = 0;
static bool lastButtonPhysicalState = HIGH;

static uint32_t lastLightReadTime = 0;
static bool isDark = false;
static bool lastDarkState = false;

static uint32_t lastTouchReadTime = 0;
static bool lastTouchDetected = false;
static bool touchSensorInitialized = false;

static uint32_t lastCO2LogicTime = 0;
static uint16_t currentCO2ppm = 400;
static uint16_t displaySmoothCO2 = 400;
static bool co2High = false;

// Tiempos vitales
static uint32_t hatchTime = 0;
static uint32_t lastFeedTestTime = 0;
static uint32_t highCO2AccumulatedMs = 0;
static uint32_t lastCO2CheckTime = 0;
static uint32_t continuousAwakeTime = 0;
static uint32_t lastAwakeCheckTime = 0;
static uint32_t lastHappinessDecayTime = 0;

// Estadísticas de partida
static int8_t currentHappiness = MAX_HAPPINESS;
static uint32_t totalPets = 0;
static uint32_t totalFeeds = 0;

static bool visualUnhealthy = false;
static bool sleepHoldFrame = false;
static bool feedRequested = false;
static bool isHatched = false;
static bool birthTriggered = false;

static uint8_t rapidFeedCount = 0;
static uint32_t firstFeedPressTime = 0;

static uint32_t eggStartTime = 0;
static uint32_t lastFrameTime = 0;

static bool isMuted = false;
static uint32_t lastMuteToggleTime = 0;
static bool lastMutePhysicalState = HIGH;

// Alertas sonoras periódicas
static uint32_t lastHungerSoundTime = 0;
static uint32_t lastSleepySoundTime = 0;
static uint32_t lastCoughSoundTime = 0;

/* ========================================================================== */
/* FUNCTION PROTOTYPES                                                        */
/* ========================================================================== */

const char* getAnimationName(AnimationState anim);
void playAnimationSound(AnimationState anim);
bool hasLightFeature(void);
bool hasCO2Feature(void);
bool hasButtonFeature(void);
bool hasTouchFeature(void);
bool isTransitionAnimation(AnimationState anim);
bool isBusyAnimation(AnimationState anim);

void drawStatsOverlay(void);
void drawFrameRaw(const uint8_t* frameData, int yOffset);
void getCurrentAnimationFrame(const uint8_t** frameData, int* yOffset);
void refreshCurrentFrame(void);
void setAnimation(AnimationState newAnim);
AnimationState getCurrentBaseState(void);
bool tryStartHealthTransition(void);
void goToBaseState(void);

void triggerDeath(DeathReason reason);
void drawDeathScreen(void);
void resetToEggState(void);

void playSoundSequence(const Note* sequence, uint8_t length);
void stopSound(void);
void updateSound(void);

void handleButton(void);
void handleLightSensor(void);
void handleTouchSensor(void);
void handleAutoHatch(void);
void handleCO2Sensor(void);
void handleMutePin(void);

void updateGameStats(void);
void checkConditionSounds(void);
bool isTouchActive(void);
void showBootMessage(void);

/* ========================================================================== */
/* AUDIO DRIVER IMPLEMENTATION                                                */
/* ========================================================================== */

void playSoundSequence(const Note* sequence, uint8_t length)
{
#if USE_BUZZER
    if (isMuted) return;

    currentSound = sequence;
    currentSoundLength = length;
    currentSoundIndex = 0;
    soundPlaying = true;
    soundLastChange = 0;
#else
    (void)sequence;
    (void)length;
#endif
}

void stopSound(void)
{
#if USE_BUZZER
    ledcWriteTone(BUZZER_CHANNEL, 0);
    ledcWrite(BUZZER_CHANNEL, 0);
    soundPlaying = false;
    currentSound = nullptr;
    currentSoundLength = 0;
    currentSoundIndex = 0;
#endif
}

void updateSound(void)
{
#if USE_BUZZER
    if (isMuted) {
        if (soundPlaying) stopSound();
        return;
    }

    if (!soundPlaying || currentSound == nullptr) return;

    uint32_t now = millis();

    if (soundLastChange == 0) {
        if (currentSound[currentSoundIndex].freq > 0) {
            ledcWriteTone(BUZZER_CHANNEL, currentSound[currentSoundIndex].freq);
            ledcWrite(BUZZER_CHANNEL, BUZZER_VOLUME);
        } else {
            ledcWriteTone(BUZZER_CHANNEL, 0);
            ledcWrite(BUZZER_CHANNEL, 0);
        }
        soundLastChange = now;
        return;
    }

    if (now - soundLastChange >= currentSound[currentSoundIndex].duration) {
        currentSoundIndex++;

        if (currentSoundIndex >= currentSoundLength) {
            stopSound();
            return;
        }

        if (currentSound[currentSoundIndex].freq > 0) {
            ledcWriteTone(BUZZER_CHANNEL, currentSound[currentSoundIndex].freq);
            ledcWrite(BUZZER_CHANNEL, BUZZER_VOLUME);
        } else {
            ledcWriteTone(BUZZER_CHANNEL, 0);
            ledcWrite(BUZZER_CHANNEL, 0);
        }

        soundLastChange = now;
    }
#endif
}

const char* getAnimationName(AnimationState anim)
{
    switch (anim) {
        case FEED:                    return "FEED";
        case IDLE:                    return "IDLE";
        case PET:                     return "PET";
        case SLEEP:                   return "SLEEP";
        case POP:                     return "POP";
        case IDLE_EGG:                return "IDLE_EGG";
        case BIRTH:                   return "BIRTH";
        case IDLE_UNHEALTHY:          return "IDLE_UNHEALTHY";
        case TRANSITION_TO_UNHEALTHY: return "TRANSITION_TO_UNHEALTHY";
        case TRANSITION_TO_HEALTHY:   return "TRANSITION_TO_HEALTHY";
        case DEAD:                    return "DEAD";
        default:                      return "UNKNOWN";
    }
}

void playAnimationSound(AnimationState anim)
{
    switch (anim) {
        case FEED:
            playSoundSequence(SOUND_FEED, sizeof(SOUND_FEED) / sizeof(SOUND_FEED[0]));
            break;
        case PET:
            playSoundSequence(SOUND_PET, sizeof(SOUND_PET) / sizeof(SOUND_PET[0]));
            break;
        case IDLE:
            playSoundSequence(SOUND_IDLE, sizeof(SOUND_IDLE) / sizeof(SOUND_IDLE[0]));
            break;
        case SLEEP:
            playSoundSequence(SOUND_SLEEP, sizeof(SOUND_SLEEP) / sizeof(SOUND_SLEEP[0]));
            break;
        case IDLE_EGG:
            playSoundSequence(SOUND_EGG, sizeof(SOUND_EGG) / sizeof(SOUND_EGG[0]));
            break;
        case BIRTH:
            playSoundSequence(SOUND_BIRTH, sizeof(SOUND_BIRTH) / sizeof(SOUND_BIRTH[0]));
            break;
        case POP:
            playSoundSequence(SOUND_POP, sizeof(SOUND_POP) / sizeof(SOUND_POP[0]));
            break;
        case IDLE_UNHEALTHY:
            playSoundSequence(SOUND_UNHEALTHY, sizeof(SOUND_UNHEALTHY) / sizeof(SOUND_UNHEALTHY[0]));
            break;
        case TRANSITION_TO_UNHEALTHY:
            playSoundSequence(SOUND_TRANSITION_UNHEALTHY, sizeof(SOUND_TRANSITION_UNHEALTHY) / sizeof(SOUND_TRANSITION_UNHEALTHY[0]));
            break;
        case TRANSITION_TO_HEALTHY:
            playSoundSequence(SOUND_TRANSITION_RECOVER, sizeof(SOUND_TRANSITION_RECOVER) / sizeof(SOUND_TRANSITION_RECOVER[0]));
            break;
        case DEAD:
            playSoundSequence(SOUND_DEATH, sizeof(SOUND_DEATH) / sizeof(SOUND_DEATH[0]));
            break;
    }
}

/* ========================================================================== */
/* LOGIC HELPERS & FEATURE AVAILABILITY                                       */
/* ========================================================================== */

bool hasLightFeature(void)  { return USE_LIGHT_SENSOR; }
bool hasCO2Feature(void)    { return (USE_CO2_SENSOR && isCO2SensorEnabled() && isCO2Connected()); }
bool hasButtonFeature(void) { return USE_BUTTON_SENSOR; }
bool hasTouchFeature(void)  { return USE_TOUCH_SENSOR; }

bool isTransitionAnimation(AnimationState anim)
{
    return (anim == TRANSITION_TO_UNHEALTHY || anim == TRANSITION_TO_HEALTHY);
}

bool isBusyAnimation(AnimationState anim)
{
    return (anim == FEED ||
            anim == PET ||
            anim == SLEEP ||
            anim == POP ||
            anim == IDLE_EGG ||
            anim == BIRTH ||
            anim == TRANSITION_TO_UNHEALTHY ||
            anim == TRANSITION_TO_HEALTHY ||
            anim == DEAD);
}

/* ========================================================================== */
/* GRAPHICS ENGINE & OVERLAY                                                  */
/* ========================================================================== */
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
void loop(void)
{
    uint32_t now = millis();

    // Gestión de estado DEAD (Pantalla de Game Over con reinicio asistido)
    if (currentAnimation == DEAD) {
        updateSound();

        bool restartRequested = (now - deathTime >= 1500UL) && (isButtonPressed() || isTouchActive());
        if (restartRequested || (now - deathTime >= DEATH_SCREEN_DURATION_MS)) {
            resetToEggState();
        }
        return;
    }

#if USE_LIGHT_SENSOR
    handleLightSensor();
#endif

#if USE_TOUCH_SENSOR
    handleTouchSensor();
#endif
    handleAutoHatch();

#if USE_BUTTON_SENSOR
    handleButton();
#endif

#if USE_CO2_SENSOR
    handleCO2Sensor();
#endif

    handleMutePin();
    updateGameStats();
    checkConditionSounds();
    updateSound();

    // Motor de Renderizado Gráfico a 5 FPS (200 ms por cuadro)
    if (now - lastFrameTime >= FRAME_TIME_MS) {
        lastFrameTime = now;

        bool advance = true;

        if (currentAnimation == SLEEP && hasLightFeature() && isDark) {
            if (currentFrame >= SLEEP_HOLD_FRAME) {
                currentFrame = SLEEP_HOLD_FRAME;
                sleepHoldFrame = true;
                advance = false;
            }
        } else {
            sleepHoldFrame = false;
        }

        if (advance) {
            currentFrame++;

            if (currentFrame >= FRAME_COUNT) {
                if (currentAnimation == IDLE_EGG) {
                    currentFrame = 0;
                }
                else if (currentAnimation == BIRTH) {
                    isHatched = true;
                    birthTriggered = false;
                    hatchTime = now;
                    lastFeedTestTime = now;
                    lastCO2CheckTime = now;
                    lastAwakeCheckTime = now;
                    lastHappinessDecayTime = now;
                    lastHungerSoundTime = now;
                    lastSleepySoundTime = now;
                    lastCoughSoundTime = now;
                    continuousAwakeTime = 0;
                    highCO2AccumulatedMs = 0;
                    currentHappiness = MAX_HAPPINESS;
                    rapidFeedCount = 0;
                    firstFeedPressTime = 0;
                    feedRequested = false;

                    goToBaseState();
                    return;
                }
                else if (currentAnimation == FEED && feedRequested) {
                    feedRequested = false;
                    goToBaseState();
                    return;
                }
                else if (currentAnimation == PET) {
                    goToBaseState();
                    return;
                }
                else if (currentAnimation == POP) {
                    // Secuencia gráfica de explosión/desvanecimiento completada obligatoriamente:
                    // Ahora pasamos formalmente al estado DEAD y dibujamos la pantalla de Game Over
                    currentAnimation = DEAD;
                    deathReason = pendingDeathReason;
                    deathTime = now;
                    playAnimationSound(DEAD);
                    drawDeathScreen();
                    return;
                }
                else if (currentAnimation == SLEEP) {
                    if (hasLightFeature() && isDark) {
                        currentFrame = SLEEP_HOLD_FRAME;
                        sleepHoldFrame = true;
                    } else {
                        goToBaseState();
                        return;
                    }
                }
                else if (currentAnimation == TRANSITION_TO_UNHEALTHY) {
                    visualUnhealthy = true;
                    setAnimation(IDLE_UNHEALTHY);
                    return;
                }
                else if (currentAnimation == TRANSITION_TO_HEALTHY) {
                    visualUnhealthy = false;
                    setAnimation(IDLE);
                    return;
                }
                else {
                    currentFrame = 0;
                }
            }
        }

        refreshCurrentFrame();
    }
}

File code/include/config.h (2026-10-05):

/**
 * @file config.h
 * @brief Master Configuration Parameters and Feature Flags for GotchiLab_.
 * @author José Escobedo Vázquez / MediaLab_
 * @license MIT
 */

#ifndef GOTCHILAB_CONFIG_H
#define GOTCHILAB_CONFIG_H

#include <stdint.h>
#include "pins_config.h"

/* ========================================================================== */
/* FEATURE FLAGS (COMPILE-TIME MODULE INCLUSION)                              */
/* ========================================================================== */

#ifndef USE_BUTTON_SENSOR
#define USE_BUTTON_SENSOR       1   ///< 1: Feed button enabled; 0: Disabled (no starvation)
#endif

#ifndef USE_TOUCH_SENSOR
#define USE_TOUCH_SENSOR        1   ///< 1: Capacitive touch enabled; 0: Auto-hatch & no petting
#endif

#ifndef USE_LIGHT_SENSOR
#define USE_LIGHT_SENSOR        1   ///< 1: LDR sleep/wake enabled; 0: Always awake (no exhaustion)
#endif

#ifndef USE_CO2_SENSOR
#define USE_CO2_SENSOR          1   ///< 1: SCD30 sensor driver compiled; 0: Complete compile-time exclusion
#endif

#ifndef USE_BUZZER
#define USE_BUZZER              1   ///< 1: PWM audio generator active; 0: Total hardware silence
#endif

#ifndef AUTO_HATCH_IF_NO_TOUCH
#define AUTO_HATCH_IF_NO_TOUCH  1   ///< 1: Egg hatches after timer if touch sensor is disabled
#endif

#define AUTO_HATCH_DELAY_MS     3000UL

#ifndef SHOW_STATS_OVERLAY
#define SHOW_STATS_OVERLAY      0   ///< 0: Immersive full-screen animation; 1: Top HUD overlay visible
#endif

/* ========================================================================== */
/* OLED DISPLAY CONFIGURATION (SSD1306)                                       */
/* ========================================================================== */

#define SCREEN_WIDTH            128
#define SCREEN_HEIGHT           64
#define OLED_RESET              -1
#define OLED_ADDRESS            0x3C

/* ========================================================================== */
/* LDR ANALOG SENSOR & SLEEP SYSTEM                                           */
/* ========================================================================== */

/**
 * @brief LDR Darkness Threshold (ESP32 ADC1 12-bit counts: 0 to 4095).
 *
 * Circuit Topology:
 *   VCC (3.3V) ---> [ LDR ] ---> V_out (PIN_LDR / GPIO34) ---> [ R_pull 10kΩ ] ---> GND
 *
 * Voltage Divider Transfer Function:
 *   V_out = VCC * (R_pull / (R_LDR + R_pull))
 *   ADC Counts = (V_out / 3.3V) * 4095
 *
 * Dynamic Response:
 *   - Ambient Room Light: R_LDR is low (~1kΩ - 5kΩ), V_out > 2.3V (ADC counts > ~2856).
 *   - Darkness / Covered: R_LDR increases sharply (> 20kΩ - 100kΩ+), V_out drops below 2.3V.
 *   - Condition `ADC < LDR_DARK_THRESHOLD` flags darkness, transitioning the creature to SLEEP.
 *
 * Multimeter Calibration Note:
 *   - 2856 counts correspond to ~2.30 V on GPIO 34.
 *   - Measure the DC voltage between GPIO 34 and GND in ambient light vs. covered state
 *     to fine-tune this value for your specific sensor batch and workshop environment.
 */
#ifndef LDR_DARK_THRESHOLD
#define LDR_DARK_THRESHOLD      2856
#endif

#define LIGHT_THRESHOLD         LDR_DARK_THRESHOLD  ///< Backward compatibility alias

/**
 * @brief LDR Debugging Telemetry Macro.
 * Set to 1 to periodically dump raw ADC counts, computed input voltage, and dark status
 * to the Serial monitor at 115200 baud to facilitate multimeter calibration.
 */
#ifndef DEBUG_LDR_CALIBRATION
#define DEBUG_LDR_CALIBRATION   0
#endif

#define LDR_DEBUG_INTERVAL_MS   1000UL
#define LIGHT_READ_INTERVAL_MS  500UL

#define MAX_TIME_AWAKE_MS       150000UL ///< Max continuous awake time before exhaustion death (2.5 min)
#define SLEEP_RECOVERY_MULTIPLIER 3      ///< Sleep recovers fatigue 3x faster than wakefulness drains it

/* ========================================================================== */
/* CO2 SENSOR DYNAMICS (SENSIRION SCD30)                                      */
/* ========================================================================== */

#define CO2_READ_INTERVAL_MS    2000UL   ///< SCD30 optical NDIR measurement interval
#define CO2_HIGH_ON_PPM         1600     ///< PPM threshold entering unhealthy / sick state
#define CO2_HIGH_OFF_PPM        1100     ///< PPM threshold recovering to healthy state (hysteresis)

#define MAX_CO2_EXPOSURE_MS     60000UL  ///< Max continuous contaminated air exposure before death (60s)
#define CO2_CLEAN_RECOVERY_MULTIPLIER 3  ///< Health recovery rate multiplier in clean air
#define CO2_COUGH_INTERVAL_MS   12000UL  ///< Sick cough sound period while air is contaminated

/* ========================================================================== */
/* BUTTON, FEEDING & SPAM EXPLOSION (POP)                                     */
/* ========================================================================== */
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

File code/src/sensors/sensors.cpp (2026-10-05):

/**
 * @file sensors.cpp
 * @brief Implementation of Sensor Abstraction Layer for GotchiLab_.
 * @author José Escobedo Vázquez / MediaLab_
 * @license MIT
 */

#include "sensors.h"
#include <Arduino.h>
#include "config/config.h"

#if USE_CO2_SENSOR
#include <Wire.h>
#include <SparkFun_SCD30_Arduino_Library.h>
static SCD30 scd30;
static bool scd30Available = false;
#endif

static bool co2SensorEnabled = false;
static int co2Value = 400;

void initSensors(bool fairModeActive)
{
#if USE_BUTTON_SENSOR
    pinMode(PIN_BUTTON, INPUT_PULLUP);
#endif

#if USE_CO2_SENSOR
    if (fairModeActive) {
        Serial.println(F("[SENSORS] Jumper de MODO FERIA detectado (GND)."));
        Serial.println(F("[SENSORS] Bypass de CO2 activado: Sensor deshabilitado, operando en linea base limpia (400 ppm)."));
        co2SensorEnabled = false;
        scd30Available = false;
        co2Value = 400;
        return;
    }

    co2SensorEnabled = true;

    // Iniciar SCD30 con auto-calibración deshabilitada por defecto para evitar distorsiones
    if (scd30.begin() == false) {
        Serial.println(F("[SENSORS] SCD30 no detectado en bus I2C (Verifique conexion SDA/SCL)"));
        scd30Available = false;
    } else {
        Serial.println(F("[SENSORS] SCD30 NDIR iniciado correctamente."));
        scd30Available = true;
        scd30.setMeasurementInterval(2);
        scd30.setAutoSelfCalibration(false);
    }
#else
    (void)fairModeActive;
    co2SensorEnabled = false;
#endif
}

void updateSensors(void)
{
#if USE_CO2_SENSOR
    if (co2SensorEnabled && scd30Available && scd30.dataAvailable()) {
        scd30.readMeasurement();
        uint16_t rawCO2 = scd30.getCO2();

        // Validacion de rango fisico plausible (SCD30: 350 - 10000 ppm)
        if (rawCO2 >= 350 && rawCO2 <= 10000) {
            co2Value = static_cast<int>(rawCO2);
        } else {
            Serial.print(F("[SENSORS] Lectura SCD30 anomala descartada: "));
            Serial.println(rawCO2);
        }
    }
#endif
}

int getCO2(void)
{
    return co2Value;
}

bool isCO2Connected(void)
{
#if USE_CO2_SENSOR
    return (scd30Available && co2SensorEnabled);
#else
    return false;
#endif
}

bool isCO2SensorEnabled(void)
{
    return co2SensorEnabled;
}

bool isButtonPressed(void)
{
#if USE_BUTTON_SENSOR
    return digitalRead(PIN_BUTTON) == LOW;
#else
    return false;
#endif
}

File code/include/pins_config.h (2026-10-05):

/**
 * @file pins_config.h
 * @brief Centralized GPIO Pinout Configuration for GotchiLab_.
 * @author José Escobedo Vázquez / MediaLab_
 * @license MIT
 */

#ifndef GOTCHILAB_PINS_CONFIG_H
#define GOTCHILAB_PINS_CONFIG_H

#include <stdint.h>

/* ========================================================================== */
/* HARDWARE PIN ASSIGNMENTS                                                   */
/* ========================================================================== */

/**
 * @name I2C Bus Configuration (SSD1306 OLED & SCD30 CO2 Sensor)
 * Shared I2C bus on ESP32 DevKit v1: SDA en GPIO 22, SCL en GPIO 21.
 */
///@{
#define PIN_I2C_SDA         22  ///< I2C Data line (Wire)
#define PIN_I2C_SCL         21  ///< I2C Clock line (Wire)
///@}

/**
 * @name User Interaction Inputs
 */
///@{
#define PIN_BUTTON          33  ///< Push button for feeding (INPUT_PULLUP, active LOW)
#define PIN_TOUCH           27  ///< TTP223 capacitive touch sensor (INPUT, active HIGH)
///@}

/**
 * @name Environmental Sensors
 */
///@{
#define PIN_LDR             34  ///< Analog LDR light sensor (ADC1_CH6, input only)
///@}

/**
 * @name Audio Actuators and Controls
 */
///@{
#define PIN_BUZZER          25  ///< Passive piezo buzzer driven via LEDC PWM
#define PIN_MUTE            32  ///< Audio mute toggle jumper/switch (INPUT_PULLUP, active LOW)
///@}

/**
 * @name Hardware Bypass Jumpers
 */
///@{
#define PIN_FAIR_MODE       26  ///< Fair Mode / CO2 bypass jumper (INPUT_PULLUP, active LOW)
#define PIN_CO2_DISABLE     PIN_FAIR_MODE
///@}

/* ========================================================================== */
/* BACKWARD COMPATIBILITY ALIASES                                             */
/* ========================================================================== */

#define OLED_SDA            PIN_I2C_SDA
#define OLED_SCL            PIN_I2C_SCL
#define BUTTON_PIN          PIN_BUTTON
#define TOUCH_PIN           PIN_TOUCH
#define LIGHT_SENSOR_PIN    PIN_LDR
#define BUZZER_PIN          PIN_BUZZER
#define MUTE_PIN            PIN_MUTE
#define FAIR_MODE_PIN       PIN_FAIR_MODE

#endif /* GOTCHILAB_PINS_CONFIG_H */

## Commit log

2026-03-16 Mejorar detección de cambios en sensor de distancia
    - Agregar inicialización explícita del sensor de distancia
    - Aumentar volumen del buzzer a 40
    - Sensor solo reacciona a cambios de estado, no a lecturas iniciales
    - Evitar activaciones falsas al encenderse el dispositivo
    [main.cpp]
2026-09-23 Añadí los archivos STL de la PCB casera
    [PlacaGotchiLab_.3mf, PlacaGotchiLab_.f3d, PlacaGotchiLab_.step]
2026-10-05 refactor(v3): pinout unificado (Touch 27, I2C 22/21) y optimización visual para OLED bicolor
2026-10-05 feat(v4): Lanzador web serial interactivo, simulador OLED en vivo, matriz modular de 7 binarios y documentacion completa
2026-10-06 Actualizar proto y diagramas
    [Esquematico.fzz]
2026-10-07 Actualización del readme para enlace a la web
2026-10-07 feat(tour): tutorial interactivo con verificacion de montaje, soporte lateral y gitignore profesional
2026-10-07 feat(docs): anadir guia.pdf en construccion con mascota y vincular en la web
2026-10-07 fix(web): anadir versionado cache-busting a css y js para despliegue directo
